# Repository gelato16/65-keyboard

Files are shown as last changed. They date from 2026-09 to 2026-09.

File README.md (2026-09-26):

# 65-keyboard
A 65% keyboard with fully custom parts designed using KiCAD and Solidworks. Made with a resin case, aluminum switch plate and soldered Epomaker silent keyswitches. 
This project is me introduction to Solidworks as someone preparing for a new robotics season, I'm not exactly a keyboard enthusiast (I might be becoming one) so I went with the essential 65% in order to keep things compact. 
features:
- 65% QWERTY layout
- Sandwich style assembly
- 7U spacebar
- Plate-mounted switches
- Custom PCB
- USB-C connection
- Custom switch plate

CAD photos:


PCB photos:




assembly guild: 
this is a sandwich style keyboard, meaning it is assembled in layers into a main base. The pcb slides easily into the main compartment followed by the switch plate, which the key switches click into. the keycaps and bezel finally lay on top and are screwed into place. 
Pictures of assembly design process below: 


Bill of materials:
https://docs.google.com/spreadsheets/d/1lCmeEfUbG34g1hUgpbVch2w63U2JIJnhS8jueZ3TIsw/edit?usp=sharing 
| Id | Designator | Footprint | Quantity | Designation | Link |
| :--- | :--- | :--- | :--- | :--- | :--- |
| 1 | MX1-MX69 | SW_MX_HS_CPG151101S11_1u | 69 | MX_SW_HS | N/A |
| 2 | U1 | LQFP-48_7x7mm_P0.5mm | 1 | STM32F072CBT6 | https://www.digikey.ca/en/products/detail/stmicroelectronics/STM32F072CBT6/4815292 |
| 3 | C1, C3, C4, C5, C6 | C_1206_3126Metric | 7 | 100nF | https://www.digikey.com/en/products/detail/kemet/C1206C104KARACTU/992167 |
| 4 | C9, C10 | C_1206_3126Metric | 2 | 1uF | https://www.digikey.ca/en/products/detail/yageo/CC1206KKX7R7BB105/302915 |
| 5 | R1 - R4 | R_1206_3126Metric | 4 | 5.1k | https://www.digikey.com/en/products/detail/stackpole-electronics-inc/RMCF1206FT5K10/1759499 |
| 6 | BOOT1, RST1 | SW_SPST_TL3342 | 2 | SW_SPST | https://jlcpcb.com/partdetail/ESwitch-TL3342F260QG/C2886894 |
| 7 | J1 | USB_C_Receptacle_HRO_TYPE-C-31-M-12 | 1 | USB_C_Receptacle_USB2.0 | https://jlcpcb.com/partdetail/C9900015525 |
| 8 | F1 | Fuse_1206_3216Metric | 1 | 500mA | https://www.lcsc.com/product-detail/C135341.html |
| 9 | U5 | C_0402_1005Metric | 1 | TXB0101 | https://www.lcsc.com/product-detail/C324081.html |
| 10 | U3 | SOT-23 | 1 | XC6206PxxxMR-Regulator_Linear | https://www.lcsc.com/product-detail/C5446.html |
| 11 | D1-D69 | D_SOD-123 | 69 | D_small | https://www.digikey.ca/en/products/detail/shenzhen-slkormicro-semicon-co-ltd/1N4148W/21853071 |
| 12 | U2 | SOT-143 | 1 | PRTR5V0U2X | https://www.digikey.ca/en/products/detail/nexperia-usa-inc/PRTR5V0U2X-215/1163690 |
| 13 | C2 | C_1206_3216Metric | 1 | 10uF | https://www.digikey.ca/en/products/detail/kemet/C1206C106K8RACTU/1090842 |
| 14 | C43, C44 | C_1206_3216Metric | 2 | 0.1uF | https://www.digikey.ca/en/products/detail/tdk/C3216X7R2A104M160AA/513969 |
| 15 | J2 | PinHeader_1x05_P2.54mm_Vertical | 1 | Conn_01x05 | https://www.digikey.ca/en/products/detail/harwin-inc/M20-9990546/3728232 |
| 16 | J3 | PinHeader_1x06_P2.54mm_Vertical | 1 | Conn_01x06 | https://www.digikey.ca/en/products/detail/sullins-connector-solutions/PEC06SAFN/859339 |
| | | | | | |
| Physical: | | | | | |
| Id | Name | quantity | link | | |
| 1 | EPOMAKER Roseveil Silent Switch Set | 1 | https://epomaker.ca/products/epomaker-roseveil-silent-switch-set?_pos=3&_sid=4f9293093&_ss=r  | | |
| 2 | DUROCK Plate Mount Stabilizer V3 | 1 | https://www.amazon.ca/dp/B0CTHT34MJ?ref=ppx_yo2ov_dt_b_fed_asin_title&th=1 | | |
| 3 | dagaladoo Coffee Cat 140key keycaps,XDA Profile,dye Sublimation PBT Custom keycap with Key Puller for Gateron MX Switch | 1 | https://www.amazon.ca/dp/B0CF1ZS6D4?ref=ppx_yo2ov_dt_b_fed_asin_title&th=1 | | |

All designs complete, assembly ongoing
(designed using Kicad, Solidworks and sketchbook)
(files with numbers ex:open2, are completed(not verified works.)

Known issues: None, 
Credits: My father for introducing me to all this. 
Sanity checked by my lovely best friend & my tech teacher

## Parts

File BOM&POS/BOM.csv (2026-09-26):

Id | Designator | Footprint | Quantity | Designation | Supplier and ref
1 | U5 | C_1206_3216Metric | 1 | TXB0101
2 | D35,D59,D69,D54,D44,D41,D47,D5,D23,D46,D38,D27,D9,D31,D24,D65,D55,D60,D34,D21,D68,D62,D26,D32,D48,D25,D20,D61,D42,D22,D43,D16,D56,D3,D1,D45,D19,D7,D67,D40,D64,D33,D37,D63,D39,D66,D58,D49,D8,D12,D53,D11,D6,D52,D2,D15,D36,D57,D17,D51,D14,D18,D30,D50,D13,D4,D28,D29,D10 | D_SOD-123 | 69 | D_Small
3 | R4,R3,R2,R1 | R_1206_3216Metric | 4 | 5.1k
4 | MX45,MX32,MX1,MX42,MX51,MX24,MX18,MX21,MX25,MX48,MX3,MX12,MX33,MX31,MX10,MX11,MX67,MX59,MX29,MX41,MX39,MX30,MX40,MX9,MX34,MX50,MX37,MX61,MX2,MX64,MX13,MX4,MX47,MX6,MX66,MX28,MX57,MX65,MX63,MX62,MX8,MX60,MX36,MX54,MX38,MX53,MX46,MX5,MX55,MX23,MX43,MX56,MX58,MX16,MX17,MX26,MX14,MX52,MX44,MX20,MX15,MX68,MX19,MX22,MX69,MX7,MX49,MX27,MX35 | SW_MX_HS_CPG151101S11_1u | 69 | MX_SW_HS
5 | U1 | LQFP-48_7x7mm_P0.5mm | 1 | STM32F072CBT6
6 | C6,C3,C4,C5,C7,C8,C1 | C_1206_3216Metric | 7 | 100nF
7 | C9,C10 | C_1206_3216Metric | 2 | 1uF
8 | BOOT1,RST1 | SW_SPST_TL3342 | 2 | SW_SPST
9 | J1 | USB_C_Receptacle_HRO_TYPE-C-31-M-12 | 1 | USB_C_Receptacle_USB2.0
10 | F1 | Fuse_1206_3216Metric | 1 | 500mA
11 | U3 | SOT-23 | 1 | XC6206PxxxMR-Regulator_Linear
12 | U2 | SOT-143 | 1 | PRTR5V0U2X
13 | C2 | C_1206_3216Metric | 1 | 10uF
14 | C43,C44 | C_1206_3216Metric | 2 | 0.1uF
15 | J2 | PinHeader_1x05_P2.54mm_Vertical | 1 | Conn_01x05
16 | J3 | PinHeader_1x06_P2.54mm_Vertical | 1 | Conn_01x04

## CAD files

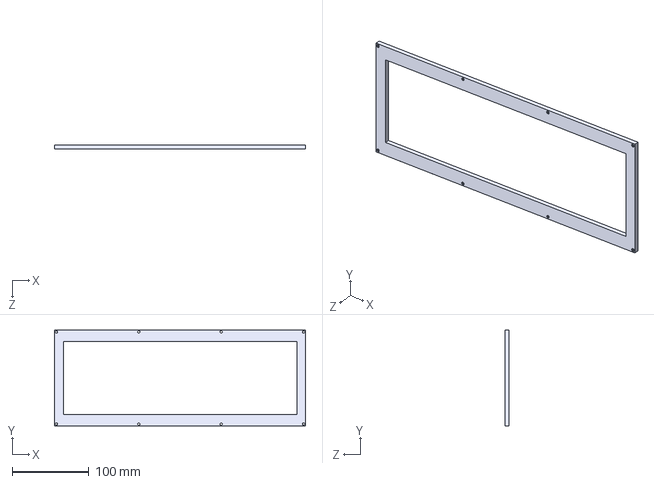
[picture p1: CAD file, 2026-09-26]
Case/bezelfinal.STEP
327.8 x 125.3 x 5.00 mm

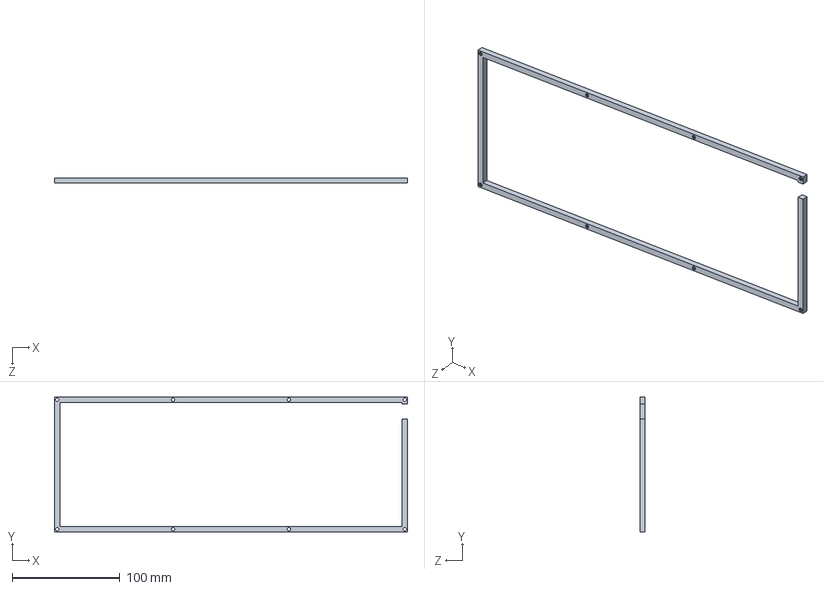
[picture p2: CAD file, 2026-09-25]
Case/openfinal.STEP
327.8 x 125.3 x 5.10 mm

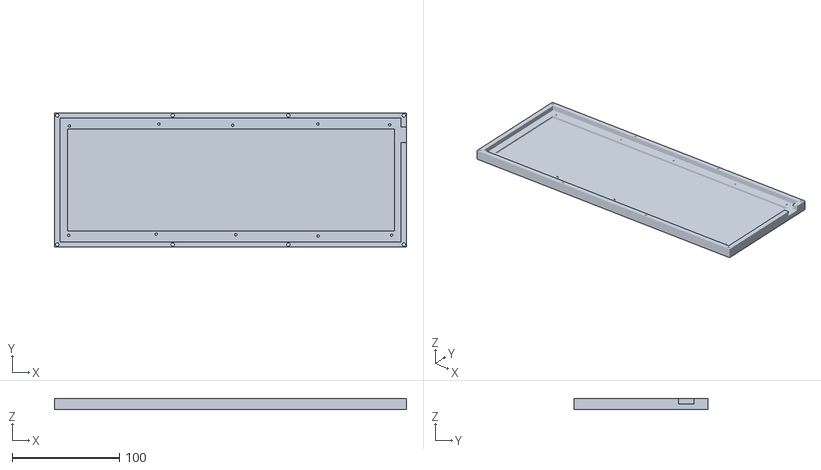
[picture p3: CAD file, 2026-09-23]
ProgressCAD/base5.STL
327.8 x 125.3 x 10.1

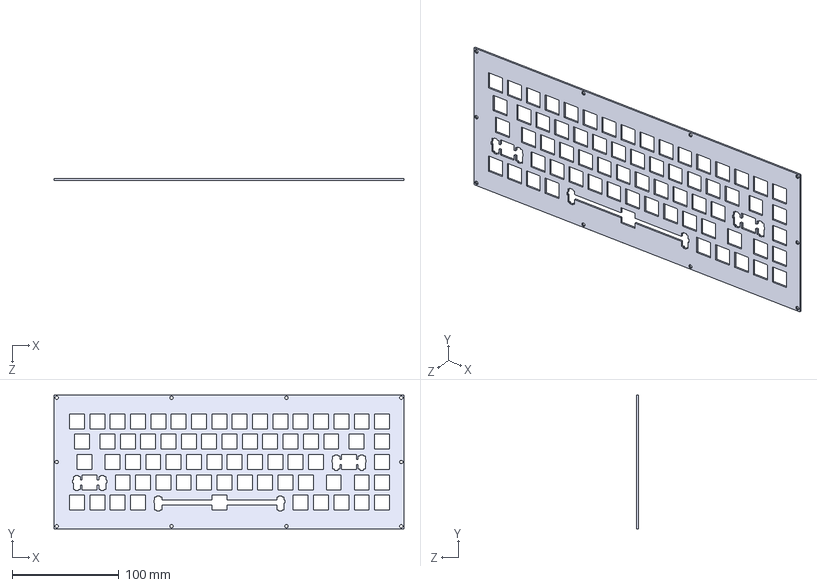
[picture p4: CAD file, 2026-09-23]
Case/platefinal.STEP
327.8 x 125.3 x 1.50 mm

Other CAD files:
ProgressCAD/bezel2.STEP
Case/switchplate2.STEP

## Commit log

2026-09-23 added pcb and scematic files
    [keyboard pcb again.kicad_pcb, keyboard pcb again.kicad_sch]
2026-09-23 added bezel and casing files
    [base5.STL, bezel2.STEP]
2026-09-23 added switch plate
    [switchplate2.STEP]
2026-09-23 added COM and positions
    (ignore the name svp)
    [helppp_bom.csv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]
2026-09-23 finalized bezel
    [bezelfinal.SLDPRT]
2026-09-23 finalized plate design
    [platefinal.STEP]
2026-09-23 added stablizers and keyswitches
    [Billofmats.csv]
2026-09-25 changed to hot swap
    [keyboard pcb again.kicad_pcb, keyboard pcb again.kicad_sch]
2026-09-25 added final open layer
    [openfinal.STEP]
2026-09-25 (should be) final pcb
    [keyboard pcb again.kicad_pcb]
2026-09-25 Add files via upload
    check error
    [keyboard pcb again.kicad_sch]
2026-09-26 Update BOM.csv
    changed microcontroller to the digikey version
    [BOM.csv]
2026-09-26 Rename keyboard pcb again.kicad_pcb to PCB/keyboard pcb again.kicad_pcb
    [keyboard pcb again.kicad_pcb]
2026-09-26 Rename keyboard pcb again.kicad_sch to PCB/keyboard pcb again.kicad_sch
    [keyboard pcb again.kicad_sch]
2026-09-26 Rename keyboard pcb again-all-pos.csv to BOM&POS/keyboard pcb again-all-pos.csv
    [keyboard pcb again-all-pos.csv]
2026-09-26 assembled parts
    PCB CAD not updated, dimentions not changed, except the USBC port
    [assem4.SLDASM]
